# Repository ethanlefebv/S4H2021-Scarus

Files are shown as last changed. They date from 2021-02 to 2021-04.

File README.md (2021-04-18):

# S4H2021-Scarus

This project is a SCARA-like robot picking and placing nuts (as in bolts, nuts, washers) with the help of a computer vision system. 

## Table of contents
1. [Hardware requirements](#hardware-requirements)
2. [Software requirements](#software-requirements)
3. [Installation](#installation)
4. [Running the program](#running-the-main-program)
5. [More information](#more-information)
6. [License](#license)

## Hardware requirements
This section lists the hardware used when developing the project. Some parts could be swapped for variants, eg. the Raspberry Pi could have more RAM or be some more recent version.
- Raspberry Pi 4 Model B, 4GB (along with a power cable, microSD card, etc.)
- OpenCR 1.0 by ROBOTIS
- XM430-W350 (2x) by ROBOTIS
- A USB webcam ([link](https://www.amazon.ca/Microphone-Otooking-Streaming-Conferencing-Recording/dp/B08HYDZ6TN))

A 3D printer is also required to print most parts. A laser cutter was also used for the slide. More details can be found [here](Mechanical_Components/README.md).

## Software requirements
This section lists the software used when developing the project. Some components could change in the future, eg. the Ubuntu version could be swapped for the most recent LTS release.

On a desktop/laptop : 
- App to ssh into the Raspberry Pi (cmd, PowerShell, WSL, PuTTY, etc.)
- Arduino IDE or arduino-cli
- This repo (mainly to upload code to the OpenCR)

On the Raspberry Pi :
- Ubuntu Server 20.04 LTS, 64 bit
- Python 3 (the modules are listed [below](#install-needed-programs-for-computer-vision))
- This repo (mainly to run the main program)

## Installation
### On a desktop/laptop :
#### Install Arduino IDE or arduino-cli and the OpenCR libraries
A laptop/desktop is required to upload code to the OpenCR (the libraries are currently not compatible with a Raspberry Pi).

##### Steps for Arduino IDE
1. Install Arduino IDE using the [official guide](https://www.arduino.cc/en/Guide)
2. Follow the instructions [here](https://emanual.robotis.com/docs/en/software/arduino_ide/#preferences) to add the additional Boards Manager URL
3. Follow the instructions [here](https://emanual.robotis.com/docs/en/software/arduino_ide/#install-the-board-package-via-boards-manager) to install the OpenCR board and libraries

##### Steps for arduino-cli
1. Install arduino-cli

    Visit the [installation page](https://arduino.github.io/arduino-cli/latest/installation/) and use the [installation script](https://arduino.github.io/arduino-cli/latest/installation/#use-the-install-script)
2. Enable command-line completion (optional but very useful)

    Follow these [steps](https://arduino.github.io/arduino-cli/latest/command-line-completion/)
3. Add the OpenCR board info to arduino-cli

    [Create a config file](https://arduino.github.io/arduino-cli/latest/getting-started/#create-a-configuration-file) to [add](https://arduino.github.io/arduino-cli/latest/getting-started/#adding-3rd-party-cores) the [OpenCR libraries](https://emanual.robotis.com/docs/en/software/arduino_ide/#preferences)
4. Install the required compiler (as mentioned [here](https://emanual.robotis.com/docs/en/software/arduino_ide/#compiler-settings)) :
    ```bash
    sudo apt install libncurses5-dev:i386
    ```
5. Install the OpenCR board and libraries : 
    ```bash
    arduino-cli core update-index
    arduino-cli core install OpenCR:OpenCR
    ```
6. If on Linux, make sure your user is part of the 'dialout' group (you need to logout and log back in after doing this step) :
    ```bash
    sudo adduser USER dialout
    ```

### On the Raspberry Pi :
#### Install needed programs for computer vision
For the computer vision, three programs/modules are needed : OpenCV for Python, Numpy and tflite_runtime. They can be installed by running the following lines :
```bash
pip install -r requirements.txt
```
```bash
pip install --extra-index-url https://google-coral.github.io/py-repo/ tflite_runtime
```

## Running the main program
### Upload the main sketch to the OpenCR
Start by connecting the OpenCR to a laptop with a USB cable. After uploading, the code runs in loop automatically. To start the main program, jump to the [next section](#run-the-main-python-program-on-the-pi).
#### Upload the sketch with Arduino IDE
1. Open the [main sketch](main/main.ino) with Arduino IDE
2. Under Tools > Board, select OpenCR
3. Under Tools > Port, select the correct port (COMX on Windows, /dev/ttyACMX on Linux, where X is a number)
4. Press the Upload button

#### Upload the sketch with arduino-cli
Go in the root directory of the repo and run the following line :
```bash
arduino-cli compile --upload -b OpenCR:OpenCR:OpenCR -p PORT main
```
where PORT is COMX on Windows and /dev/ttyACMX on Linux (where X is a number, modify the index accordingly).

### Run the main Python program on the Pi
Start by connecting the OpenCR to the Raspberry Pi. Next, connect to the Raspberry Pi using ssh.

On the Pi, go in the root directory of the repo and run the following line :
```bash
python3 main.py ARGS
```
and replace ARGS with the necessary arguments (they can be listed by running `python3 main.py --help`).

## More information

Further information about the vision system can be found [here](Computer_Vision/README.md).

A detailed BOM and assembly instructions are listed [here](Mechanical_Components/README.md).

A diagram of the program structure can be found [here](main/README.md).

A video explaining the project can be watched [here](https://youtu.be/wnFR6_URe1g) (in French with English subtitles).

## License
Apache Version 2.0

See [LICENSE](LICENSE)

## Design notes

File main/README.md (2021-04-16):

# _main_ folder
This folder contains all the C++ code that runs on the OpenCR. The purpose of the different files is [described here](#files) and a diagram of the [program structure](#program-structure) is also shown.

## Files
- __actuators.cpp__ : This file contains all the functions to control the robot's movements (motors and solenoids).
- __comm_functions.cpp__ : This file contains all the functions required for the communication with the Raspberry Pi over the Serial port.
- __inverse_kinematics.cpp__ : This file contains the math functions to convert a 2D coordinate to motor angles.
- __nut.h__ : This file contains the definition of the Nut type.
- __main.ino__ : This is the main sketch file (main program for the OpenCR).

## Program structure
The following image shows the main structure of the program running on the Raspberry Pi and the progam running on the OpenCR.

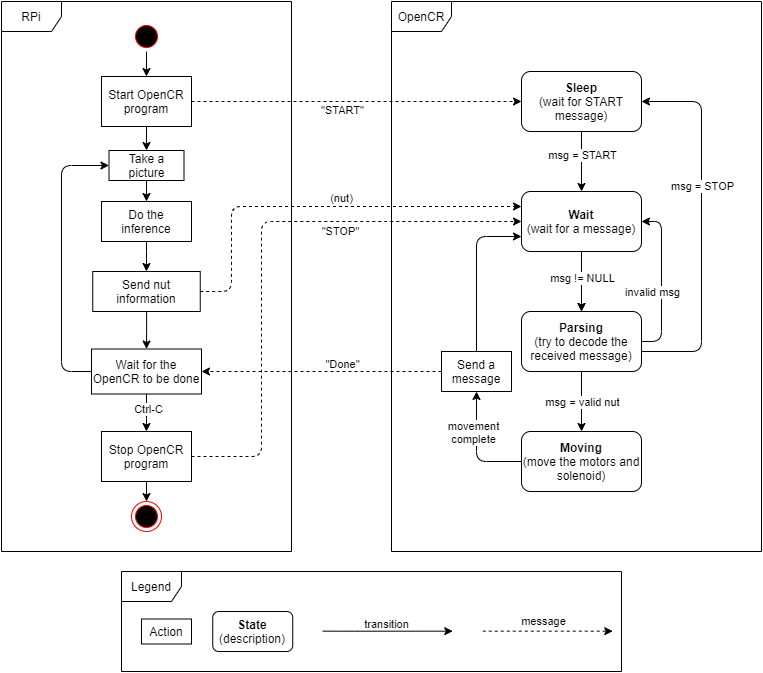
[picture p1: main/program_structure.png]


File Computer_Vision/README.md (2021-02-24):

# Computer Vision
This section presents the way the computer vision pipeline works and how the training for the custom models was done.

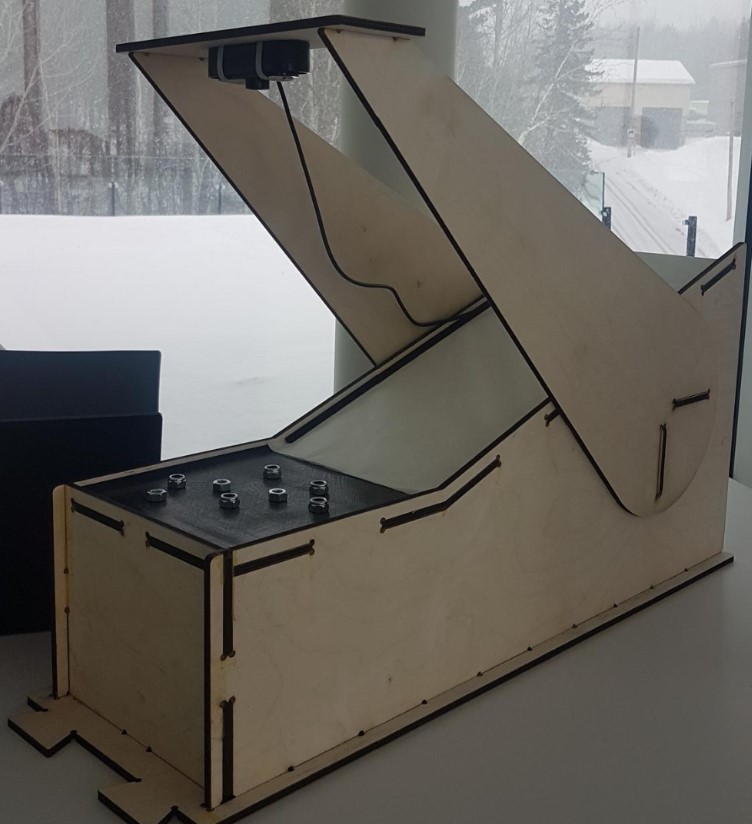
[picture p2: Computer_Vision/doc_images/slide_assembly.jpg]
slide


## Training
The repository is not a tutorial on how to train a custom yolov4 model, but a summary of the process is presented here. 
As of now, yolov4 is not available on either PyTorch, nor TensorFlow, therefore we had to use the Darknet framework. 

### 1- Darknet installation
In order to install the Darknet framework we followed the instructions from the official YoloV4 GitHub (https://github.com/AlexeyAB/darknet).

We also followed TheCodingBug's Youtube playlist for further details on the installation steps (https://www.youtube.com/watch?v=FE2GBeKuqpc&list=PLUE9cBml08yiahlgN1BDv_8dAJFeCIR1u&index=2).

### 2- Data collection
We collected the data in a setting resembling as closely as possible our actual use case. Therefore, we had to build the slide before collecting our data, so we could take pictures of the nuts at a fixed distance but with varying lights input. This allows the model to train itself on a more representative data set to make sure it is as accurate as possible in this setting.

### 3- Labeling
We labeled our data using a yolo compatible software called labelImg, from this GitHub: https://github.com/tzutalin/labelImg.

### 4- Model training
We used the default Darknet framework to train our data. We simply followed the steps explained in the official YoloV4 GitHub (https://github.com/AlexeyAB/darknet).
Since we wanted to run the inference on a Raspberry Pi, we used YoloV4's "tiny" version.

### 5- Converting the model from Darknet to TensorFlow Lite
In order to run the inference smoothly on the Raspberry Pi, we also converted the model to TensorFlow Lite using this GitHub: https://github.com/hunglc007/tensorflow-yolov4-tflite.

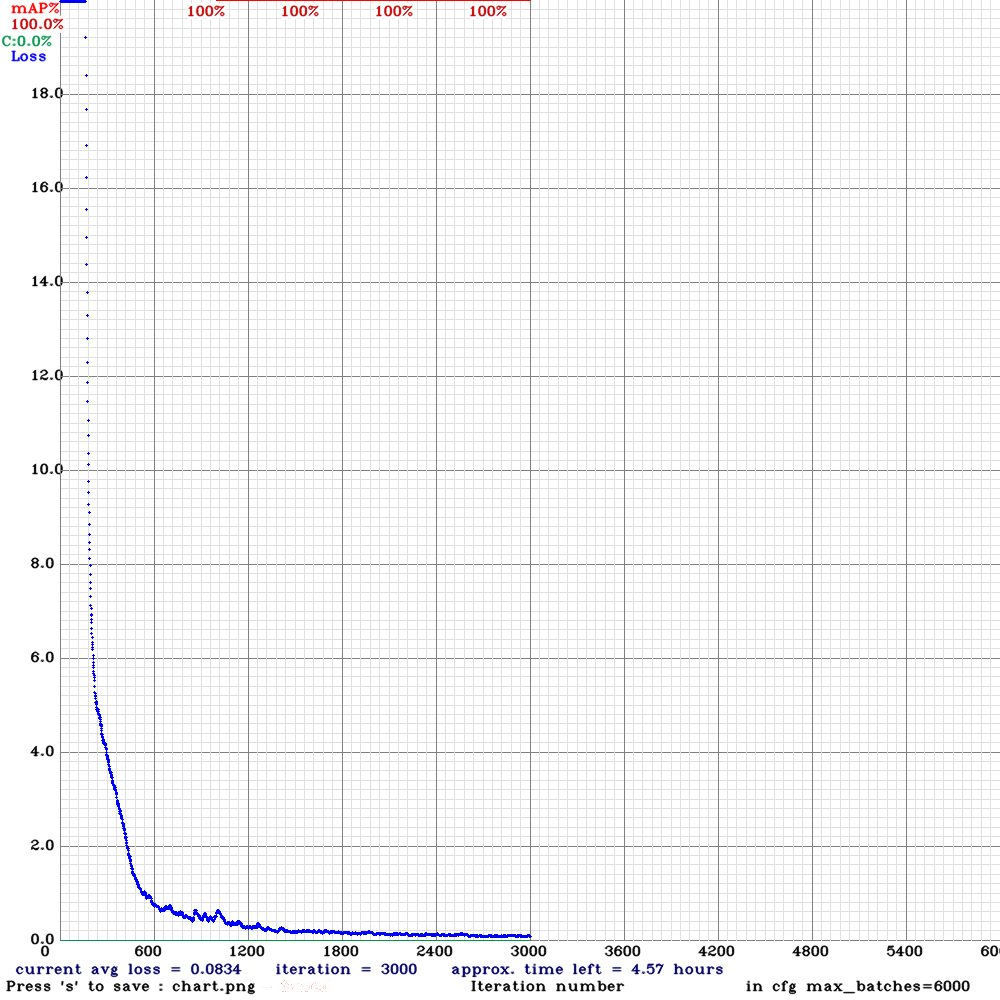
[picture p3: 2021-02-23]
Computer_Vision/doc_images/training_loss_graph.png

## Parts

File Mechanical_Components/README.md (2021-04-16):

# Mechanical assembly
This section lists the steps for the full assembly of the SCARA robot.

### BOM
Robot:
-   2 x Carbon tubing Ø 10 mm x 285 mm (or aluminium)
-   2 x Aluminium tubing Ø ½” x 185 mm
-   2 x DYNAMIXEL XM430-W350-T
-   16 x 608-ZZ Bearings
-   6 x Screws M3 x 10 mm (Tighten arms)
-   2 x Screws M3 x 25 mm (Motor joints arms)
-   2 x Screws M3 x 35 mm (Motor joints threaded rods)
-   2 x Screws M3 x 20 mm (Coupling threaded rods)
-   12 x Nuts M3
-   3 x Screws M8 x 50 mm (Joints)
-   3 x Nuts M8
-	2 x Threaded rods 5/16-18 x 60 mm
-	16 x Screws M2.5 x 10 mm (Dynamixels' sides)
-	8 x Screws M2.5 x 20 mm (Dynamixels' bottom)
-	8 x Screws M2 x 8 mm (Dynamixels' coupling)

Gripper:
-	2 x MOSFET FQP30N06L
-	2 x MOSFET driver MCP1407-E/P
-	4 x Resistance 2000 ohms
-	2 x Resistance 100 ohms
-	2 x Diode 1N4934RLG
-	1 x Linear solenoid (DC 12V 5N 10mm)
-	1 x Magnet wire roll (30 AWG)
-   1 x Fishing wire thread
-	4 x Screws M4 x 15 mm (Fan)
-	2 x Screws M3 x 8 mm (linear solenoid fixation)
-	1 x Screws M3 x 30 mm (Solenoid core)
-   2 x Nuts M3
-	1 x Screws M2 x 12 mm (Electromagnet fixation)
-	1 x Nuts M2

Robot's base and slide:
-	2 x Birch plywood 4x8 feet
-	1 x Wood glue
-	1 x Parchment paper (Slide bed)
-	7 x Screws M10 x 50 mm or 3/8-24 x 2 in (Adjustable stands)
-	14 x Nuts M10 or 3/8-24
-	4 x Screws M4 x 20 mm (Motor bases fixation)
-	4 x Screws M4 x 25 mm (Dove tails fixation)
-	12 x Nuts M4

General:
-	1 x OpenCR 1.0
-	4 x Screws M4 x 15 mm (OpenCR fixation)
-	4 x Nuts M4
-	1 x Raspberry Pi 4B 4GB
-	4 x Screws M2.5 x 12 mm (Raspberry Pi fixation)
-	4 x Nuts M2.5
-	1 x Webcam Otooking 1080p (any USB webcam would do the job)
-	2 x Tie-wraps (Camera fixation)
-	1 x Electric tape roll
-	1 x 1 kg PLA roll
-	1 x Loctite bottle
-	10 x Nuts M5
-	10 x Lock-nuts M5

### 3D prints
All the 3D print files are located in the STL folder

### 2D laser cuts
All the laser cut files are located in the DXF folder

### Joints
3D print all the .stl files located in the STL/Robot/Joints sub-folder
1.  Press fit the 4 bearings in their 2 housings.
2.  Pass a M8 x 50 mm screw through 1 housing, then through a spacer, and through the other housing.
3.  Apply Loctite to the protruding end of the M8 screw and screw the M8 nut with as much force as possible
    without impairing the bearings' rotation. (Let the Loctite cure)
4.  Clip the 2 caps to each end of the joint.
5.  Repeat steps 1 to 4 for the other joints.

Here's the [joint's assembly video](VIDEOS/ASSY_JOINT.mp4).

### Motors
3D print all the .stl files located in the STL/Robot/Motors sub-folder
1.  Put the 3D printed coupling on the Dynamixel's coupling and screw it on with 4x M2 x 8 mm screws.
2.  Drill 2 holes in a threaded rod as per the CAD.
3.  Insert the threaded rod in the 3D printed coupling and screw it in with a M3 x 20 mm screw and a M3 nut.
4.  Insert bearings in the bearing housing. They should be press fitted.
5.  Put the cap bearings over the bearings (Clip on the bearing housing).
6.  Screw the subassembly (bearings + housing + caps) on the motor. Screw it with 8x M2.5 x 10 mm screws in the motor's casing.
7.  Screw the motor joint on the threaded rod with a M3 x 35 mm and a M3 nut.
8.  Screw a motor 3D printed motor stand to the base of the motor with 4x M2.5 x 20 mm.
9.  Repeat steps 1. to 8. for the other motors.

Here's the [motor's assembly video](VIDEOS/SUPPORT_MOTOR.mp4).

### Gripper
3D print all the .stl files located in the STL/Gripper sub-folder
1.  Screw the LIFTING_SOLENOID_HOLDER and a M3 nut within it onto the linear solenoid with a M2 x 12 mm screw and a M2 nut.
2.  Pass a M3 x 30 mm screw through the LIFTING_SOLENOID_CORE and use a M3 nut on the other end.
3.  Fill the LIFTING_SOLENOID_CORE by rolling magnet wire arround it with a drill.
4.  Wrap the magnet wire in electric tape while ensuring that the 2 ends of the magnet wire are still protruding.
5.  Screw the protruding end of the M3 x 30 mm screw into the encastrated M3 nut from step 1.
    (Optional: Add washers with hot glue to the end of the M3 x 30 mm screw to widen the contact surface between the nuts and the gripper)
6.  Use fishing wire and thread it around the assembly to prevent the lifting solenoid from spinning freely around the linear solenoid.
6.  Slide the linear solenoid into the SOLENOID_COVER and crew it into the SOLENOID_DOOR with 2x M3 x 8 mm screws.
7.  Clip the SOLENOID_DOOR into the SOLENOID_COVER.
8.  Screw the fan in the SOLENOID_COVER with 4x M4 x 15 mm.
9.  Screw the gripper onto the end of the robot.

Here's the [gripper's assembly video](VIDEOS/ASSY_GRIPPER.mp4).

### Arms
1.  Put tape at both ends of the long arms (around one layer but could be more).They will be press fitted, so it is best if they are tight and do not slip.
2.  Insert one long arm in the top part of the joint with the screw thread for the gripper facing down and the other long arm in the bottom piece of the same joint.
3.  Insert the other end of the 2 long arms in the top part of 2 other joints.
4.  Insert the short arms in the bottom parts of those joints.
5.  Put the M3 x 10 mm screws and nuts in the joints to tighten it around the arms.
6.  Insert the short arms into the motor joints and screw them in with 2x M3 x 35 mm screws and 2x M3 nuts.

Here's the [arms' assembly video](VIDEOS/ASSY_SCARA_ROBOT.mp4).

### Robot's base
Laser cut all the .dxf files located in the DXF/ROBOT_BASE sub-folder
1.  Assemble all the wooden parts as per the CAD.
2.  Apply wood glue in every slots and between the side walls and the slider support.
3.  Secure the assembly with clamps and let the glue cure.
4.  Screw the OpenCR with 4x M4 x 15 mm and 4x M4 nuts to the slider.
5.  Screw the Raspberry Pi with 4x M2.5 x 12 mm and 4x M2.5 nuts to the slider.
6.  Insert the slider into the assembly.
7.  Screw the 4 stands (4x M10 x 50 mm screws + 8x M10 nuts) in the 4 corresponding 10 mm holes.
8.  Screw the 2 motor stands on the top plate with 8x M4 x 20 mm screws and 8x M4 nuts.

### Slide
Laser cut all the .dxf files located in the DXF/SLIDE sub-folder

3D print the STL/PLA_BUCKET.stl file with a PLA color constrasting with the items to pick up
1.  Assemble all the wooden parts as per the CAD.
2.  Apply wood glue in every slots and between the 3D printed bucket and the wooden bucket.
3.  Secure the assembly with clamps and let the glue cure.
4.  Apply a few layers of parchment paper onto the surface of the slide (where the nuts will slide) and scotch tape the edges.
6.  Screw the 3 stands (3x M10 x 50 mm screws + 6x M10 nuts) in the 3 corresponding 10 mm holes.
7.  Screw the 4 dove tails to the front of the base with 4x M4 x 25 mm and 4x M4 nuts.
8.  Fix the camera on the camera support using tie-wraps passing through the holes.
 
### Final assembly of the SCARUS
1.  Insert the slide's dove tail into the robot's base's dove tail shaped slots.
2.  Adjust the gripper's height relative to the slide's bucket with the 7 stands.
3.  You're done, press start!

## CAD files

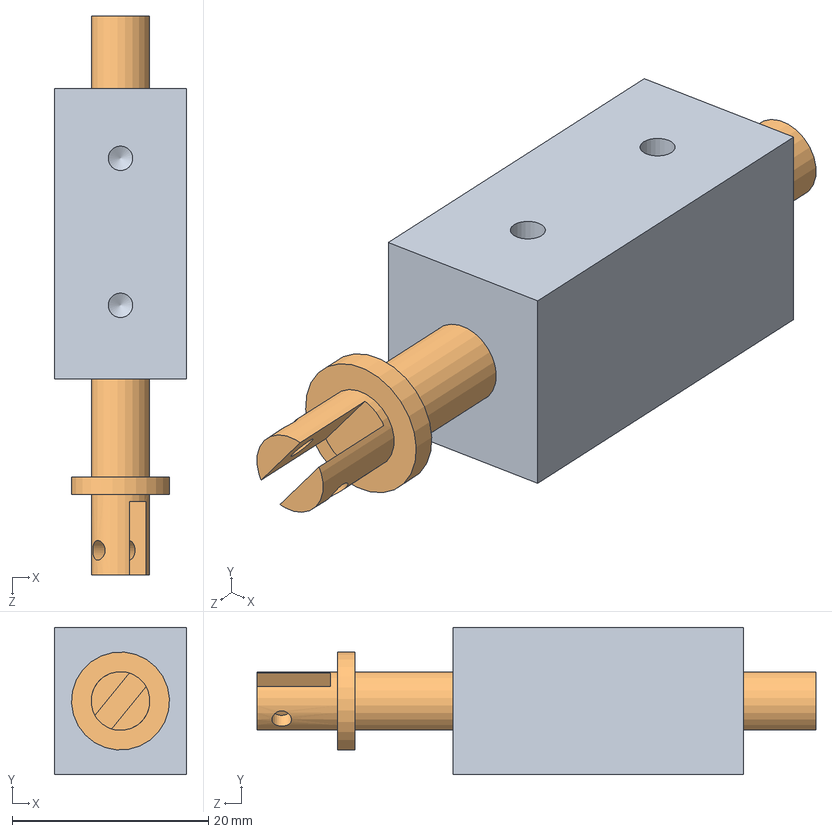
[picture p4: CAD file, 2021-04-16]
Mechanical_Components/ASSY_SCARUS/ASSY_ROBOT/ASSY_GRIPPER_QUICK_CONNECT/ASSY_SOLENOID/ASSY_SOLENOID.SLDASM
13.5 x 15.0 x 57.0 mm
SOLENOID_CASE
SOLENOID_SLIDER

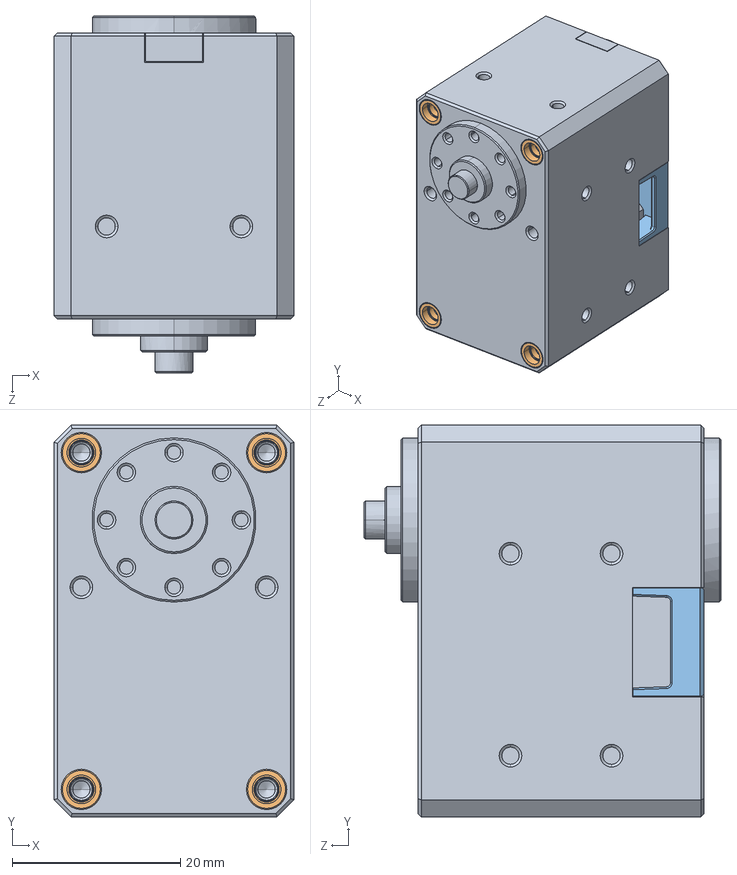
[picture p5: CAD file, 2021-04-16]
Mechanical_Components/ASSY_SCARUS/ASSY_ROBOT/XM430-W350.SLDASM
28.5 x 46.5 x 42.4 mm
X-430_IDLE.stp
X-430_SPACER_RING.stp x 8
X-430_CVR_CABLE.stp

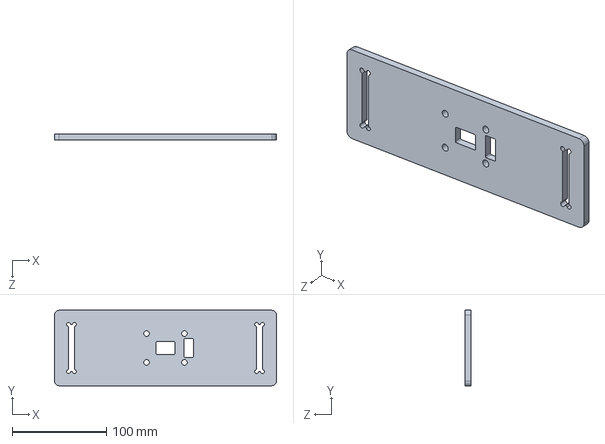
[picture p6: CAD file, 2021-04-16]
Mechanical_Components/ASSY_SCARUS/ASSY_SLIDE/MAIN_CAM_SUPPORT.SLDPRT
235.0 x 80.0 x 6.35 mm

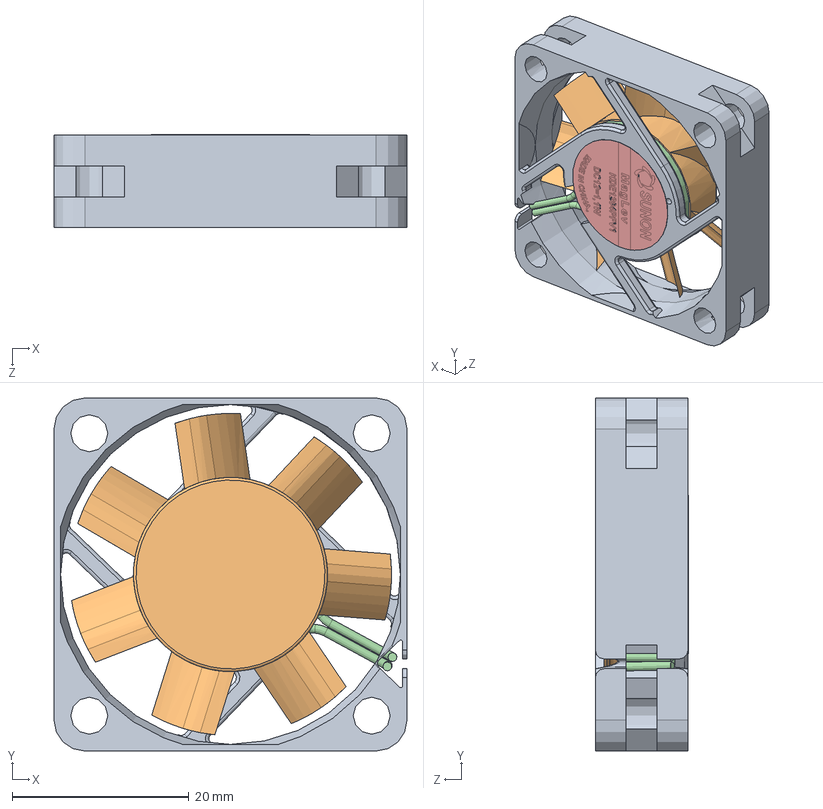
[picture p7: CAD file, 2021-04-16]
Mechanical_Components/ASSY_SCARUS/ASSY_ROBOT/ASSY_GRIPPER_QUICK_CONNECT/ASSY_FAN/Cooler 40x40x10 SBORKA.SLDASM
40.0 x 40.0 x 10.6 mm
Cooler 40x40x10 body
Cooler Blades
Cooler Motor
Cooler pcb
Sticker SUNON

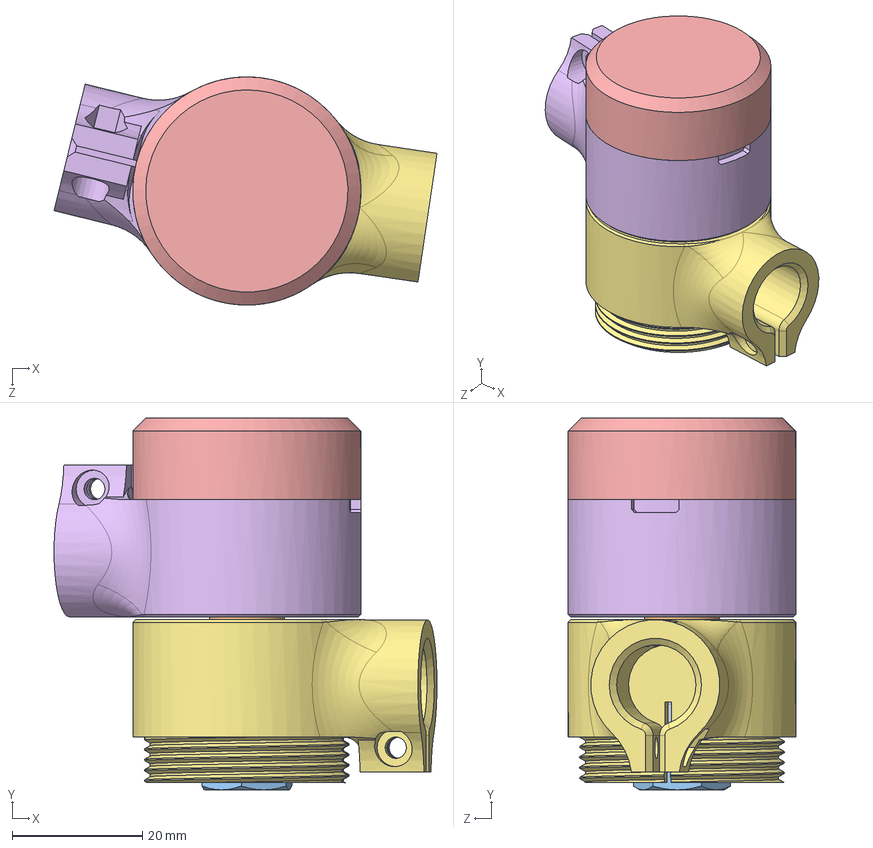
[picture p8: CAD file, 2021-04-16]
Mechanical_Components/ASSY_SCARUS/ASSY_ROBOT/ASSY_JOINTS/ASSY_JOINT_GRIPPER.SLDASM
58.7 x 57.0 x 35.0 mm
Ball Bearing 608ZZ x 4
SPACER x 3
hex bolt gradeb_iso
hex nut gradec_iso
CAP_BOLT
JOINT_STD_V2
JOINT_STD_V2_GRIPPER

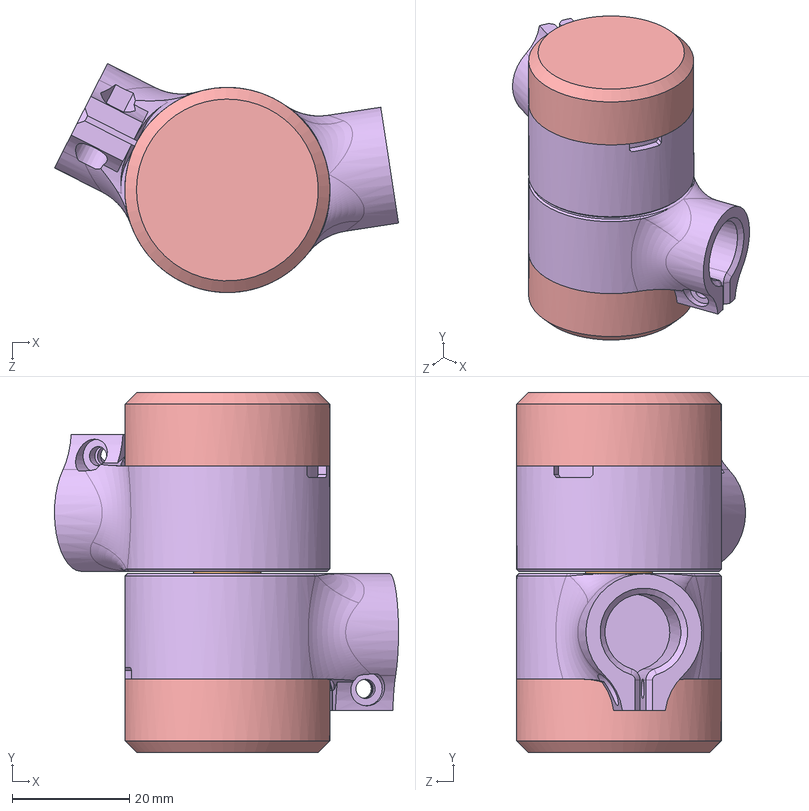
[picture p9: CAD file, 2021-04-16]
Mechanical_Components/ASSY_SCARUS/ASSY_ROBOT/ASSY_JOINTS/ASSY_JOINT.SLDASM
58.7 x 61.4 x 39.1 mm
Ball Bearing 608ZZ x 4
SPACER x 3
hex bolt gradeb_iso
hex nut gradec_iso
CAP_BOLT x 2
JOINT_STD_V2 x 2

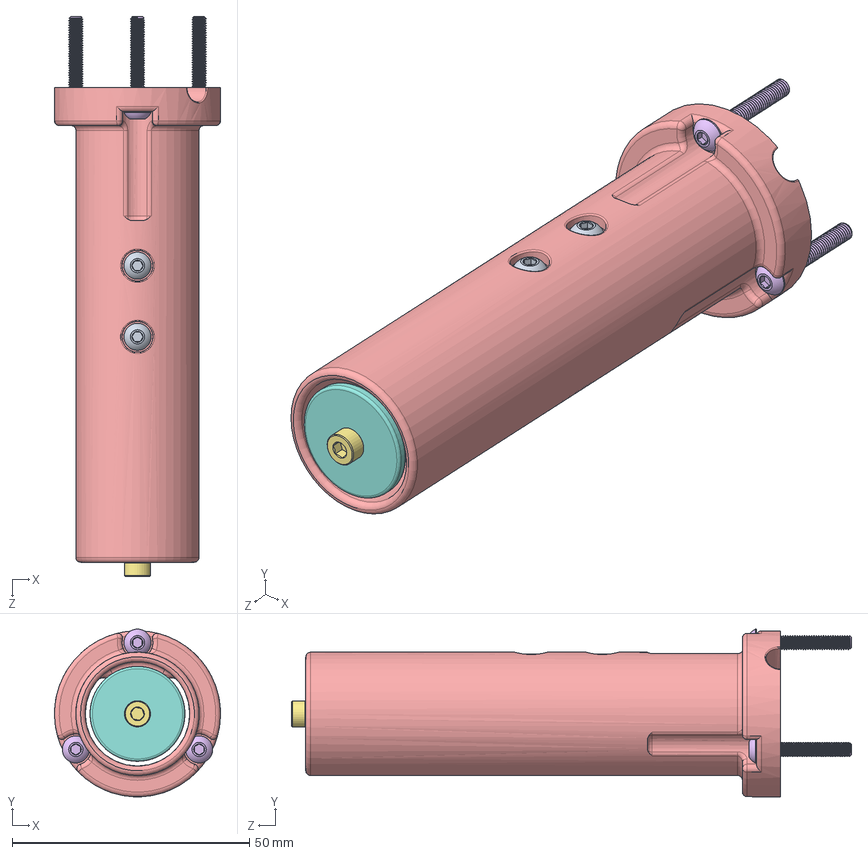
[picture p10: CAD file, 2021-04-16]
Mechanical_Components/ASSY_GRIPPER/ASSY_GRIPPER.SLDASM
35.0 x 35.3 x 118.0 mm
SOLENOID_CASE
SOLENOID_SLIDER
LIFTING_SOLENOID_HOLDER
90592A085_STEEL HEX NUT x 2
SOLENOID_FIXTURE
92095A185_BUTTON HEAD HEX DRIVE SCREW x 3
91290A130_BLACK-OXIDE CLASS 12.9 SOCKET HEAD CAP SCREW
LIFTING_SOLENOID_CORE
92095A179_BUTTON HEAD HEX DRIVE SCREW x 2

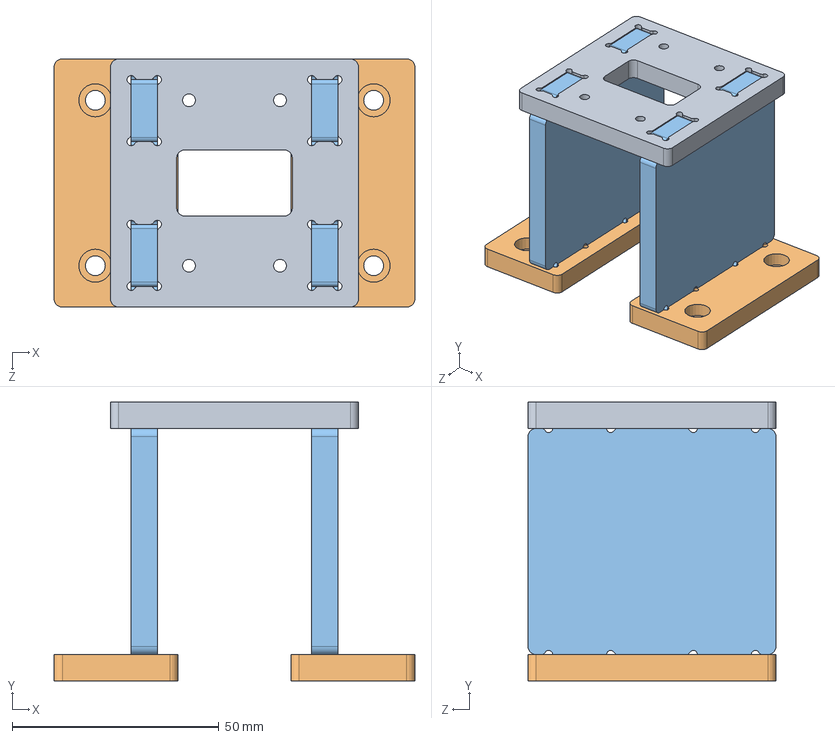
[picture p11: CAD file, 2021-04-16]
Mechanical_Components/MOTOR_STAND/ASSY_MOTOR_STAND_HIGH_WOOD.SLDASM
87.3 x 67.4 x 60.0 mm
MOTOR_STAND_TOP_WOOD
MOTOR_STAND_BOT_WOOD x 2
MOTOR_STAND_HIGH_SIDE_WOOD x 2

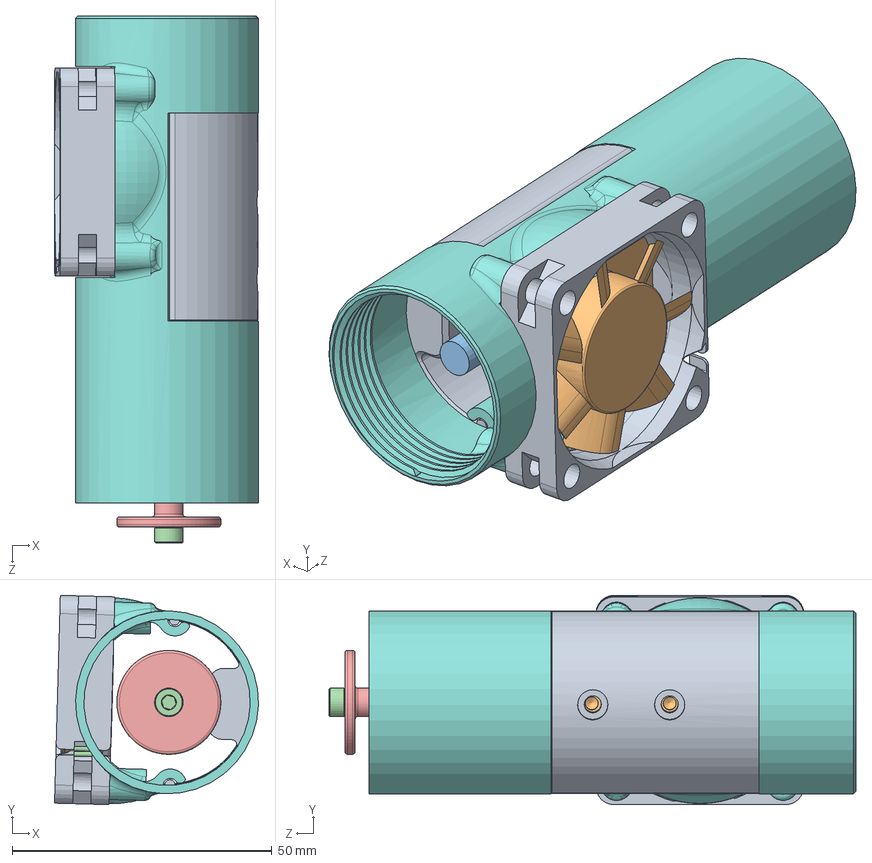
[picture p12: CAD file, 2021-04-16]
Mechanical_Components/ASSY_SCARUS/ASSY_ROBOT/ASSY_GRIPPER_QUICK_CONNECT/ASSY_GRIPPER.SLDASM
39.2 x 40.3 x 101.3 mm
SOLENOID_DOOR
SOLENOID_CASE
SOLENOID_SLIDER
91290A130_BLACK-OXIDE CLASS 12.9 SOCKET HEAD CAP SCREW
LIFTING_SOLENOID_CORE
90592A085_STEEL HEX NUT x 2
LIFTING_SOLENOID_HOLDER
SOLENOID_COVER_V2
Cooler 40x40x10 body
Cooler Blades
Cooler Motor
Cooler pcb
Sticker SUNON

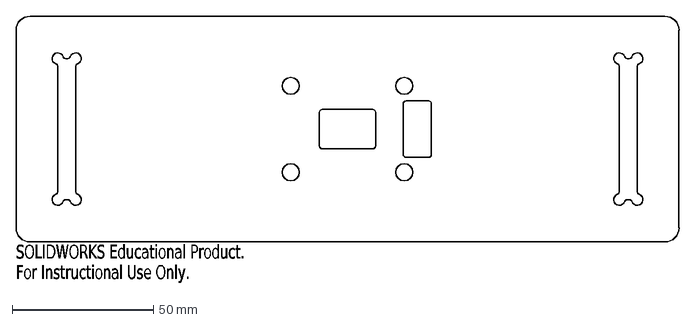
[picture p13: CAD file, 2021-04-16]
Mechanical_Components/DXF/SLIDE/SLIDE_MAIN_CAM_SUPPORT.DXF
SOLIDWORKS Educational Product.
For Instructional Use Only.

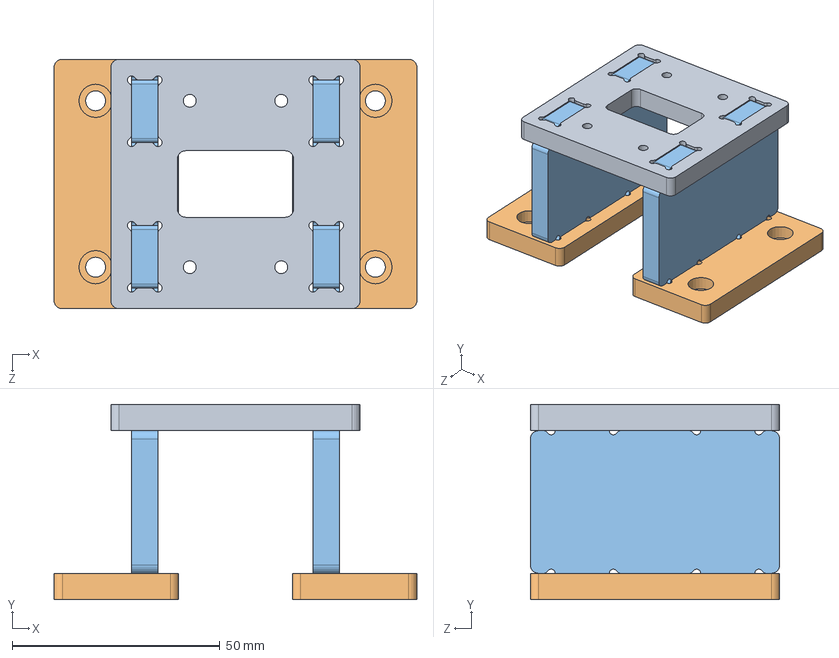
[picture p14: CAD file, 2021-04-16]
Mechanical_Components/MOTOR_STAND/ASSY_MOTOR_STAND_WOOD.SLDASM
87.3 x 47.0 x 60.0 mm
MOTOR_STAND_TOP_WOOD
MOTOR_STAND_BOT_WOOD x 2
MOTOR_STAND_SIDE_WOOD x 2

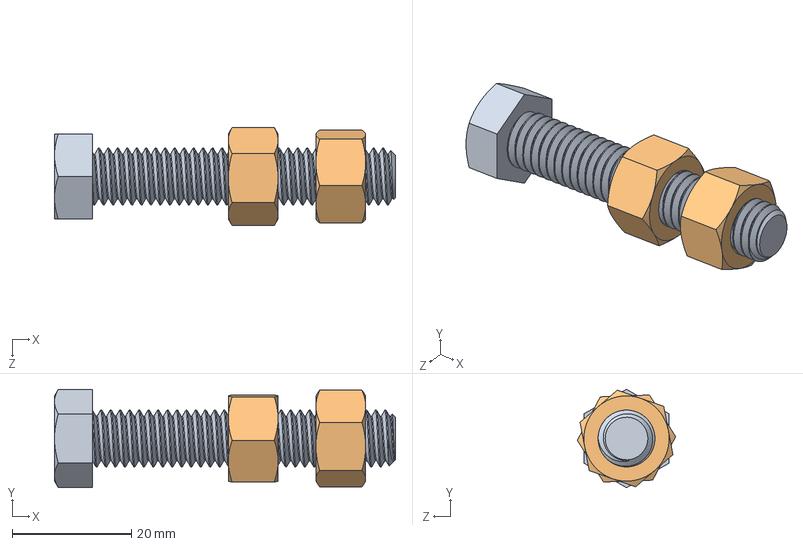
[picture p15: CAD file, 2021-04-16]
Mechanical_Components/ASSY_SCARUS/ASSY_SLIDE/ASSY_STAND.SLDASM
57.1 x 16.5 x 16.5 mm
91309A632_LOW-STRENGTH ZINC-PLATED STEEL CAP SCREW
90473A031_LOW-STRENGTH STEEL HEX NUT x 2

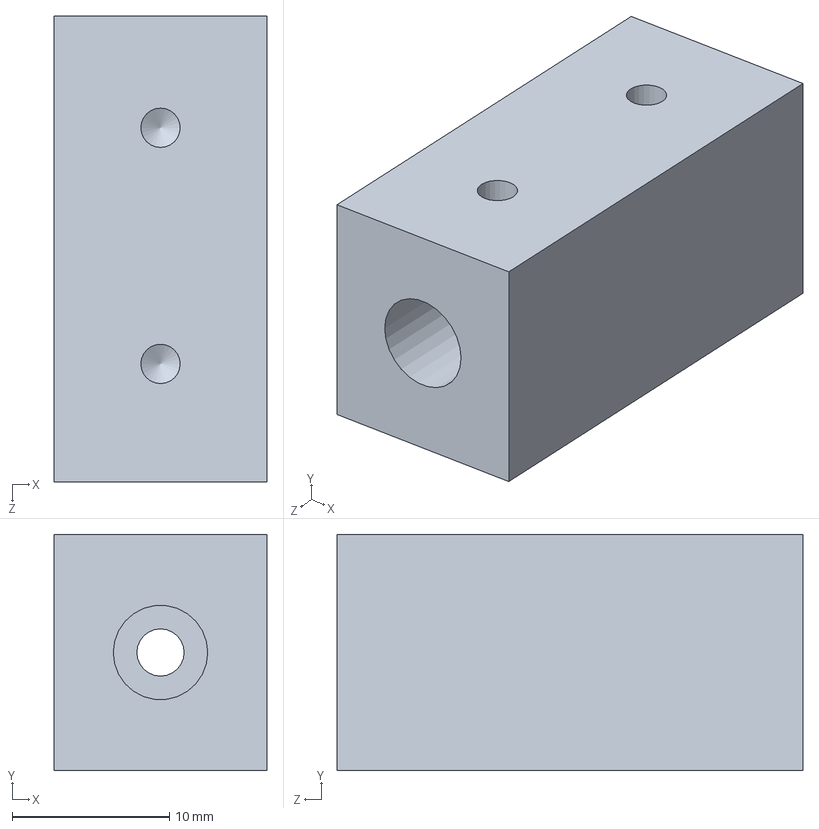
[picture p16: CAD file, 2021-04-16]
Mechanical_Components/ASSY_GRIPPER/ASSY_SOLENOID/SOLENOID_CASE.SLDPRT
13.5 x 15.0 x 29.6 mm

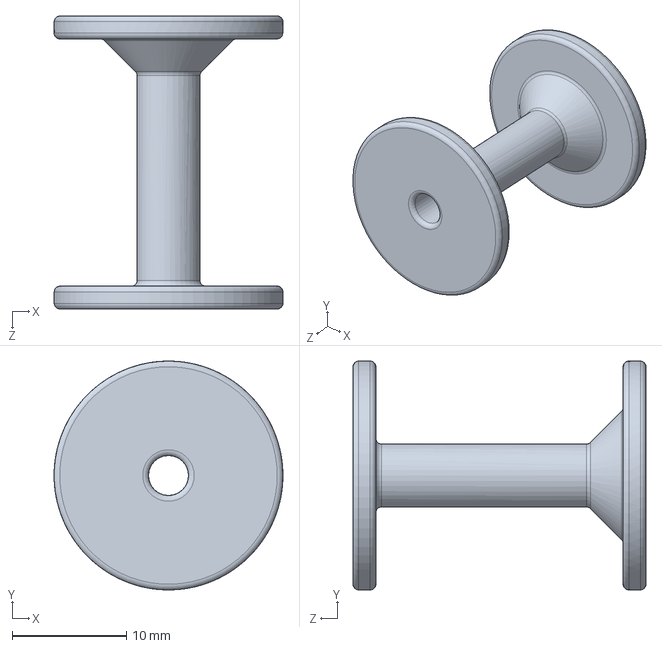
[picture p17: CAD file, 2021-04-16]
Mechanical_Components/ASSY_GRIPPER/LIFTING_SOLENOID_CORE.SLDPRT
20.0 x 20.0 x 25.6 mm

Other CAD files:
Mechanical_Components/ASSY_GRIPPER/ASSY_SOLENOID.SLDASM
Mechanical_Components/ASSY_SCARUS/ASSY_ROBOT/ARM_SEGMENT_1.SLDPRT
Mechanical_Components/ASSY_SCARUS/ASSY_ROBOT/ASSY_GRIPPER_QUICK_CONNECT/ASSY_FAN/Cooler Blades.SLDPRT
Mechanical_Components/ASSY_SCARUS/ASSY_ROBOT/ASSY_GRIPPER_QUICK_CONNECT/ASSY_SOLENOID/SOLENOID_SLIDER.SLDPRT
Mechanical_Components/92095A177_BUTTON HEAD HEX DRIVE SCREW.SLDPRT
Mechanical_Components/92095A181_BUTTON HEAD HEX DRIVE SCREW.SLDPRT
Mechanical_Components/93475A210_TYPE 18-8 STAINLESS STEEL FLAT WASHER.SLDPRT
Mechanical_Components/93475A240_TYPE 18-8 STAINLESS STEEL FLAT WASHER.SLDPRT
Mechanical_Components/ASSY_GRIPPER/90592A085_STEEL HEX NUT.SLDPRT
Mechanical_Components/ASSY_GRIPPER/91290A130_BLACK-OXIDE CLASS 12.9 SOCKET HEAD CAP SCREW.SLDPRT
Mechanical_Components/ASSY_GRIPPER/92095A179_BUTTON HEAD HEX DRIVE SCREW.SLDPRT
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

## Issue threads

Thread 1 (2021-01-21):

Être capable de faire de l'inférence avec un model .tflite généré par des weights de yoloV4

robinmailhot, 2021-01-21:
Capable de faire rouler un code costum avec .tflite mais pas essayer avec un model convertie de darknets yoloV4.

robinmailhot, 2021-01-21:
Il est faisable de transérer les weights en un model .tflite.
code here : https://github.com/theAIGuysCode/tensorflow-yolov4-tflite

Closed 2021-01-26.

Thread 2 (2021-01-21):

Read about ROS (Robot Operating System)

ethanlefebv, 2021-01-21:
ROS is something that could be useful for this project. I will read more about it to find out whether it could really be used in this project.

ethanlefebv, 2021-01-21:
ROS seems to be a good idea to keep looking into.
It allows to run processes ("nodes") and exchange information between each other with a publisher/subscriber pattern. Since the project is open source, a lot of packages exist already and could be useful. For instance, ([rosserial_arduino](http://wiki.ros.org/rosserial_arduino)) would be useful to communicate with the Arduino/OpenCR. There also seems to be something to communicate with OpenCV and USB cameras which would most probably be helpful for the vision part.

ethanlefebv, 2021-01-21:
Tutorial on ROS & Arduino IDE : [tutorial](http://wiki.ros.org/rosserial_arduino/Tutorials/Arduino%20IDE%20Setup)

ethanlefebv, 2021-01-28:
I also discovered that there are two versions of ROS : ROS1 and ROS2. ROS2 is obviously more recent and would be the best option for forward compatibility, as long as we can use it with an Arduino/OpenCR.
I will now mark this issue as Done and start installing ROS2 and doing some tests.

Closed 2021-01-28.

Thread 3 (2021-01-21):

S'assurer de la faisabilité de transférer un model yoloV4 en .tflite

robinmailhot, 2021-01-21:

ethanlefebv, 2021-01-21:
@robinmailhot, je te recommande d'ajouter un commentaire lorsque tu mets une tâche comme Done ou Closed, ainsi que d'ajouter un label pour indiquer si c'est complété, wontfix, etc.

robinmailhot, 2021-01-21:
Il est faisable de transérer les weights en un model .tflite.
code here : https://github.com/theAIGuysCode/tensorflow-yolov4-tflite

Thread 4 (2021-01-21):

Find a good way to communication between Python (RPi) and Arduino/OpenCR

ethanlefebv, 2021-01-21:
As done in the S3 project, we could use JSON files as a way to communicate. We should however explore other alternatives.

ethanlefebv, 2021-01-28:
Using Serial as a method of communication seems rather barebones. I believe ROS would be a good way to do it. I will start working on Issue #7 (installing and testing ROS) and mark this issue as Done. If ROS doesn't work for whatever reason, I'll go back and reopen this to find an alternative.

Closed 2021-02-02.

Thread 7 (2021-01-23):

Install and test ROS on a Raspberry Pi

ethanlefebv, 2021-01-23:
It would be wise to test ROS before really commiting to it.

ethanlefebv, 2021-01-23:
We should also try to communicate with an Arduino.

ethanlefebv, 2021-01-31:
Installing ROS2 on the Raspberry Pi turned out to be rather straightforward following the tutorials. Communication was tested by running two test nodes provided with the installation.

Closed 2021-01-31.

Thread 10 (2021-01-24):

Résoudre le système avec fonction par itération dans Matlab

Tilec99, 2021-01-24:

Tilec99, 2021-01-24:
Le squelette du code est réalisé, par contre le cancer pogne dedans, reste a reverifier si une erreur c'est glissé dans les matrices ou si la technique utiliser en ce moment est mauvaise.![SCREENSHOT_MATLAB.png]

Tilec99, 2021-01-27:
Le code converge vers une réponse, mais celle-ci est mauvaise. Passé beaucoup de temps avec Nicolas Quaegebeur pour essayer de debugger, mais aucun résultat n'a fonctionné encore.

Je vais essayer de faire de la recherche ailleurs voir si je peux pas trouver une solution.

Closed 2021-02-16.

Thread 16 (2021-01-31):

Create demo of communication between Pi and Arduino

ethanlefebv, 2021-01-31:
As discussed with the team, ROS2 might be overkill for this project (even if learning ROS2 would probably be worth it in the long run). Now that ROS2 was installed and tested, I will write a short Python script that will communicate with an Arduino board to test the Serial communication.

The OpenCR board is planned to be used instead of an Arduino Mega but I don't have yet access to it, so the demo will be done with an Arduino. The code should still run fine on an OpenCR. This will eventually be tested.

ethanlefebv, 2021-02-02:
I have an Arduino sketch that reads and writes to the Serial port, and a Python script that uses the same Serial port to read and write stuff from/to the Arduino. If we decide to not use ROS2 for the project, these programs would be a starting point.

Closed 2021-02-02.

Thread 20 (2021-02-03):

Create communication demo with ROS2

ethanlefebv, 2021-02-03:
ROS2 was successfully installed and tested with a template/tutorial. I will now write some sample code to test the communication and see how it will be achieved on the Pi and the OpenCR/Arduino.

If I have issues with ROS2, I will try with ROS1 instead.

ethanlefebv, 2021-02-06:
As discussed with the team, ROS2 will be put on hold for the moment. The Serial communication was already tested (#16) and works fairly well. If we have the time in the future, we could reconsider using ROS, but Serial comm. will most likely be well enough.

Closed 2021-02-06.

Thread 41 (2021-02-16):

Rod's support

AnthonyTurgeon-B, 2021-02-16:
CAD of motors' support between the rod and the bearings that support the load.

Tilec99, 2021-02-22:
i think its the same as CAD motor support, 2 times the same task???

AnthonyTurgeon-B, 2021-02-22:
As-tu compris la difference, je m'etais mal exprimer mdr?

Tilec99, 2021-02-22:
yes, the name of the part is important

Tilec99, 2021-02-22:
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

Closed 2021-02-22.

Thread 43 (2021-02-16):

CAD of motors' support (box)

AnthonyTurgeon-B, 2021-02-16:
CAD of a support, a wooden box, that can be assemble with the slide and that will support the robot by the motors. Holes are cut to indicate where to put the motors.  It will also have premade holes on a false bottom to fix the OpenCR and Raspberry Pi and holes for the wires and plugs.

Tilec99, 2021-02-22:
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

Closed 2021-03-24.

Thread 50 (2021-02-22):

CAD of the rod's support bearing covers

AnthonyTurgeon-B, 2021-02-22:
CAD the pieces that protect the bearings that are supporting the rod that support the robot's frame.
There are two of these: one on the top of the support, the other at the bottom.

Tilec99, 2021-02-22:
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

Closed 2021-03-14.

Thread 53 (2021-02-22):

Assembly of scarus V1

Tilec99, 2021-02-22:
Assembly of the robot with the 3D printed pieces, the furnished motors and standard hardware.

Closed 2021-02-24.

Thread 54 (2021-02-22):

CAD of the robot (SCARUS v1)

AnthonyTurgeon-B, 2021-02-22:
CAD of the assembly of the robot. This assembly is composed of 4 rods, 2 motors, 3 joints and the different supports needed.

Closed 2021-03-14.

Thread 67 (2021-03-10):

Test the current demo with the motors

ethanlefebv, 2021-03-10:
The current demo finds nuts and sends the data to the OpenCR. The next step is to send the coordinates to the inverse kinematics function and move the motors to the calculated angles.

ethanlefebv, 2021-03-14:
The current code succeeds at getting good angles from the inverse kinematics function and moving the motors.

Closed 2021-03-14.

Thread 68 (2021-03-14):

Test the current code on the Raspberry Pi

ethanlefebv, 2021-03-14:
Since the final product will use a Raspberry Pi, it should be tested as soon as possible.

ethanlefebv, 2021-03-14:
The code almost worked instantly, we only had to add some "sync" mechanics on the OpenCR to wait for data to be available (the inference is notably slower on the Pi than on a typical laptop).

ethanlefebv, 2021-03-14:
Related to #65

Closed 2021-03-16.

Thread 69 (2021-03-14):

Enhance the installation instructions in the README

ethanlefebv, 2021-03-14:
The current steps listed for installing arduino-cli should be expanded to include Arduino IDE (since the code for the OpenCR has to be uploaded from a laptop/desktop, it doesn't have to be executed exclusively from the console). The steps should also be clearer.

A section could be created to explicitely specify how and what to upload to the OpenCR.

Closed 2021-03-24.

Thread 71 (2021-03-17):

Modification of SCARUS V1 and reprinting

Tilec99, 2021-03-17:
Fixing some mechanical issue with the robot. The joints have been modified to eliminate collisions issues.

Closed 2021-03-17.

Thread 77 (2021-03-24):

Test the robot with motors

robinmailhot, 2021-03-24:
need to be sure the robot moves correctly if the motors are activated

Closed 2021-03-24.

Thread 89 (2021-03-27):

Add cooling to the gripper

Tilec99, 2021-03-27:
Solenoids are really bad actuators, they are inefficient, so by adding cooling we hope to get a higher duty cycle.

Closed 2021-03-31.

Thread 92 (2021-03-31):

Fitting the electrical part to robot

Tilec99, 2021-03-31:
-The custom mosfet switch needed some adjustment and a clean up (debugging)
-Making of the gripper harness with connector

Closed 2021-03-31.

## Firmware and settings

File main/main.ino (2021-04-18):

/*
Project:     SCARUS
Description: Main code that moves the motors. To be run from the OpenCR.
Authors: Alec Gagnon,      gaga2120
         Étienne Lefebvre, lefe1001
         Robin Mailhot,    mair1803
         Charles Caya,     cayc2401
*/

// ---------- Libraries ----------
#include <Arduino.h>
#include <DynamixelWorkbench.h>
#include <vector>
#include "comm_functions.hpp"
#include "actuators.hpp"
#include "inverse_kinematics.hpp"
#include "nut.hpp"


// ---------- Enumerations ----------
enum class State { Sleep, Wait, Parse, Moving };

// ---------- Constants ----------
// --- Motors ---
const std::vector<uint8_t> MOTOR_IDS = { (const uint8_t)1, (const uint8_t)2 };
const uint8_t LINEAR_PIN = 5;
const uint8_t SOLENOID_PIN = 6;

// ---------- Variables ----------
// --- Motors ---
DynamixelWorkbench dyna;

// --- Data ---
State current_state = State::Sleep;
String msg = String();
Nut current_nut;
float motor_angles[4];

// ---------- Main functions ----------
void setup()
{
    const int BAUDRATE = 115200;
    Serial.begin(BAUDRATE);

    init_motors(dyna, MOTOR_IDS, motor_angles, LINEAR_PIN);
    pinMode(LINEAR_PIN, OUTPUT);
    pinMode(SOLENOID_PIN, OUTPUT);
}

void loop()
{
    switch (current_state)
    {
        case State::Sleep:
        {
            // Waiting for the signal to start the program
            send_data("Waiting for the START command.");
            delay(100);
            msg = get_data();
            if(should_start(msg))
            {
                send_data("Starting the program.");
                start_motors(dyna, MOTOR_IDS);
                go_to_home(dyna, MOTOR_IDS, motor_angles, LINEAR_PIN);
                current_state = State::Wait;
            }
            break;
        }

        case State::Wait:
        {
            // Waiting for data on the serial port
            msg = get_data();
            if (msg.length() != 0)
            {
                current_state = State::Parse;
            }
            break;
        }

        case State::Parse:
        {
            // Try to parse the received message
            Nut nut = parse_nut(msg);

            if (nut.is_valid)
            {
                current_state = State::Moving;
                current_nut = nut;
            }
            else if (should_stop(msg))
            {
                send_data("Stopping the program.");
                stop_motors(dyna, MOTOR_IDS);
                current_state = State::Sleep;
            }
            else
            {
                // Message is invalid
                current_state = State::Wait;
            }
            break;
        }

        case State::Moving:
        {
            go_to_pick(current_nut, dyna, MOTOR_IDS, motor_angles, LINEAR_PIN, SOLENOID_PIN);
            go_to_drop(current_nut, dyna, MOTOR_IDS, motor_angles, LINEAR_PIN, SOLENOID_PIN);
            send_data("Done");
            
            current_state = State::Wait;
            break;
        }
    }
    delay(10);
}

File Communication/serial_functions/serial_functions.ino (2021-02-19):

#include <Arduino.h>

class Coord
{
public:
    Coord(int x = 0, int y = 0)
    {
        _x = x;
        _y = y;
    }
    ~Coord() {}

    int get_X()
    {
        return _x;
    }
    int get_Y()
    {
        return _y;
    }

    String print()
    {
        return "X:" + String(_x) + " | Y:" + String(_y);
    }

private:
    int _x;
    int _y;
};


bool run = false;
const char ID = '1';
String DESC = "This program parses coordinates and sends back the read coordinate.";

void setup()
{
    Serial.begin(9600);
}

void loop()
{
    String msg = get_data();
    msg = check_for_start_stop_signal(msg);

    if (run)
    {
        // This is the main loop for the program.

        Coord received_coord = parse_coord(msg);
        send_data("I received: " + received_coord.print());
    }
    else
    {
        send_data("Waiting for the START command.");
        delay(1000);
    }
}

/// Verify if the current message says to start
/// or stop the program.
/// Return the message.
String check_for_start_stop_signal(String msg)
{
    if (msg == "START")
    {
        send_data("Starting the program. " + DESC);
        msg = get_data();
        run = true;
    }
    else if (msg == "STOP")
    {
        send_data("Stopping the program.");
        run = false;
    }
    return msg;
}

/// Read data from the serial port.
/// Ignore the message if it was sent by this device.
/// Return the received data.
String get_data()
{
    String tmp = Serial.readStringUntil("\n");
    String data = "";
    // A string of one char would mean the message only contains
    // the ID of the sender, so ignore the message
    if (tmp.length() > 1)
    {
        // The first char is the ID of the sender: if the ID is this
        // device's ID, ignore the message
        if (tmp[0] != ID)
        {
            data = tmp.substring(1);
        }
    }
    return data;
}

/// Parse a coordinate from a String.
/// Return the coordinate if it was valid, else
/// return (9999,9999).
Coord parse_coord(String data)
{
    Coord coord;
    int separator_index = data.indexOf('|');
    if (separator_index != -1)
    {
        String x = data.substring(0, separator_index);
        String y = data.substring(separator_index + 1);
        coord = Coord(x.toInt(), y.toInt());
    }
    else
    {
        coord = Coord(9999, 9999);
    }
    return coord;
}

/// Write data to the serial port.
/// Prepend the ID of the sender to the message.
/// Return the sent message.
void send_data(String data)
{
    String message = ID + data;
    Serial.println(message);
    return message;
}

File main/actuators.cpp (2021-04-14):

#include "actuators.hpp"
#include "inverse_kinematics.hpp"
#include "nut.hpp"
#include <Arduino.h>
#include <DynamixelWorkbench.h>
#include <vector>

/// Custom function to convert an angle to a value that can be sent
/// to the Dynamixel motors.
int32_t degrees_to_int(const float angle)
{
    return (int32_t)(4095*(angle+180)/360);
}

/// Moves the motors to a wanted position.
void move_to_pos(DynamixelWorkbench& motor, const std::vector<uint8_t>& motor_IDs, float angles[4])
{
    for (size_t i = 0; i < motor_IDs.size(); ++i)
    {
        motor.goalPosition(motor_IDs[i], degrees_to_int(angles[i]));
    }
}

/// Calls move_to_pos and waits until the movements are complete.
bool move_to_pos_wait(DynamixelWorkbench& motor, const std::vector<uint8_t>& motor_IDs, float angles[4])
{
    bool move_complete = false;
  
    for (int i = 0; i < 100 && !move_complete; ++i)
    {
        move_to_pos(motor, motor_IDs, angles);
         
        int32_t pos0 = 0;
        int32_t pos1 = 0;

        motor.getPresentPositionData(motor_IDs[0], &pos0);
        motor.getPresentPositionData(motor_IDs[1], &pos1);

        move_complete = abs(degrees_to_int(angles[0]) - pos0) < 10 && abs(degrees_to_int(angles[1]) - pos1) < 10;
        
        delay(10);
    }
}

void init_motors(DynamixelWorkbench& motor, const std::vector<uint8_t>& motor_IDs, float motor_angles[4], const uint8_t LINEAR_PIN)
{
    for (size_t i = 0; i < motor_IDs.size(); ++i)
    {
        const char* motor_name = i+"";
        uint16_t model_number = 0;
        const char* error_message;
        motor.init(motor_name, 57600, &error_message);
        motor.ping(motor_IDs[i], &model_number, &error_message);
        motor.jointMode(motor_IDs[i], 150, 0, &error_message);
        motor.torqueOn(motor_IDs[i]);
    }
}

void go_to_home(DynamixelWorkbench& motor, const std::vector<uint8_t>& motor_IDs, float motor_angles[4], const uint8_t LINEAR_PIN)
{
    for (int i = 0; i < sizeof(HOMEANGLES)/sizeof(HOMEANGLES[0]); ++i)
    {
        motor_angles[i] = HOMEANGLES[i];
    }
    linear_high(LINEAR_PIN);
    delay(1000);
    move_to_pos_wait(motor, motor_IDs, motor_angles);
    analogWrite(LINEAR_PIN, 0);
}

void start_motors(DynamixelWorkbench& motor, const std::vector<uint8_t>& motor_IDs)
{
    for (size_t i = 0; i < motor_IDs.size(); ++i)
    {
        motor.torqueOn(motor_IDs[i]);
    }
}

void stop_motors(DynamixelWorkbench& motor, const std::vector<uint8_t>& motor_IDs)
{
    for (size_t i = 0; i < motor_IDs.size(); ++i)
    {
        motor.torqueOff(motor_IDs[i]);
    }
}

void linear_high(const uint8_t LINEAR_PIN)
{
    analogWrite(LINEAR_PIN, 170);
}

void solenoid_high(const uint8_t SOLENOID_PIN)
{
    analogWrite(SOLENOID_PIN, 255);//analogWrite(SOLENOID_PIN, 150);
}

void pick(const uint8_t LINEAR_PIN, const uint8_t SOLENOID_PIN)
{
    analogWrite(LINEAR_PIN, 0);
    solenoid_high(SOLENOID_PIN);
    delay(500);
    linear_high(LINEAR_PIN);
}

void drop(const uint8_t LINEAR_PIN, const uint8_t SOLENOID_PIN)
{
    analogWrite(LINEAR_PIN, 0);
    analogWrite(SOLENOID_PIN, 0);
}

void go_to_pick(const Nut& current_nut, DynamixelWorkbench& motor, const std::vector<uint8_t>& motor_IDs, float motor_angles[4], const uint8_t LINEAR_PIN, const uint8_t SOLENOID_PIN)
{
    linear_high(LINEAR_PIN);
    delay(500);
    inverse_kinematics(current_nut.coord.x, current_nut.coord.y, motor_angles);
    move_to_pos_wait(motor, motor_IDs, motor_angles);
    delay(500);
    pick(LINEAR_PIN, SOLENOID_PIN);
    delay(500);
}

void go_to_drop(const Nut& current_nut, DynamixelWorkbench& motor, const std::vector<uint8_t>& motor_IDs, float motor_angles[4], const uint8_t LINEAR_PIN, const uint8_t SOLENOID_PIN)
{
    float dropX = 0.097;
    float dropY = 0.150;
    
    if (current_nut.type == 0)
    {
        dropX = -0.085;
        dropY = 0.250;
    }
    else if (current_nut.type == 1)
    {
        dropX = 0.280;
        dropY = 0.250;
    }

    inverse_kinematics(dropX, dropY, motor_angles);
    move_to_pos_wait(motor, motor_IDs, motor_angles);
    delay(100);
    drop(LINEAR_PIN, SOLENOID_PIN);
}

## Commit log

2021-02-03 #16 : Simple demo to test communication between a Pi and an Arduino/OpenCR using the Serial port.
2021-02-19 took out some prints for debugging
2021-02-21 #45 Wrote functions to send and receive nut data
2021-02-21 added kinematics function C++
2021-02-22 Add installation steps for arduino-cli
2021-02-23 Added @Tilec99's code to interact with the motors
2021-02-24 Add files via upload
    Every CAD files of SCARUS v1 needed for its fabrication
    [BASE.DXF, BUCKET.DXF, BaseRobotSupport.DXF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]
2021-02-24 added readme to CAD
2021-03-12 #67 Added motor movement with main demo
2021-03-17 working version of pin tests
2021-03-17 working servo+PINOUT test
2021-03-29 #90 Added security features in inverse kinematics
2021-03-30 #91 Cleaned up OpenCR main file, and added actuators.h and .cpp files
2021-03-31 #93 Set up communication from camera to robot
2021-03-31 Fixed tests and code cleanup in comm functions
    [functions.py]
2021-03-31 Nut movement pipeline works
2021-04-01 Revert "Spelling fixed"
    This reverts commit afa7dda15fa9a9102456baa60dd144d63df3d437.
    Revert last commit because it somehow reverted the previous commit
    [actuators.cpp, main.ino]
2021-04-07 2 Dynamixel motors
2021-04-08 #101 FIRST NUT!!!
2021-04-09 Camera calibration
2021-04-11 Fixed bug on Pi
    [actuators.cpp]
2021-04-14 Fixed waiting for movement bug
    [actuators.cpp]
2021-04-16 Added mechanical doc and CADs
    [5_16_THREADED_ROD.SLDPRT, 90473A031_LOW-STRENGTH STEEL HEX NUT.SLDPRT, 90576A117_ZINC-PLATED CLASS 8 STL NYLON-INSERT LOCKNUT.SLDPRT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]
2021-04-16 Add assembly videos for Scarus
2021-04-16 Updated README with links to assembly videos
2021-04-16 Renamed folders
    [5_16_THREADED_ROD.SLDPRT, 90473A031_LOW-STRENGTH STEEL HEX NUT.SLDPRT, 90576A117_ZINC-PLATED CLASS 8 STL NYLON-INSERT LOCKNUT.SLDPRT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]
2021-04-18 Added proper handling of invalid message
    As it was, the OpenCR would have been stuck in the Parse state if an invalid nut/message was received. With this fix, the message will be ignored and the OpenCR will go back to the Wait state.
    [main.ino]
